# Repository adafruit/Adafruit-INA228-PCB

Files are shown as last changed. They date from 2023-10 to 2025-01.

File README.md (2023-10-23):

## Adafruit INA228 - I2C 85V, 20-bit High or Low Side Power Monitor - STEMMA QT / Qwiic PCB

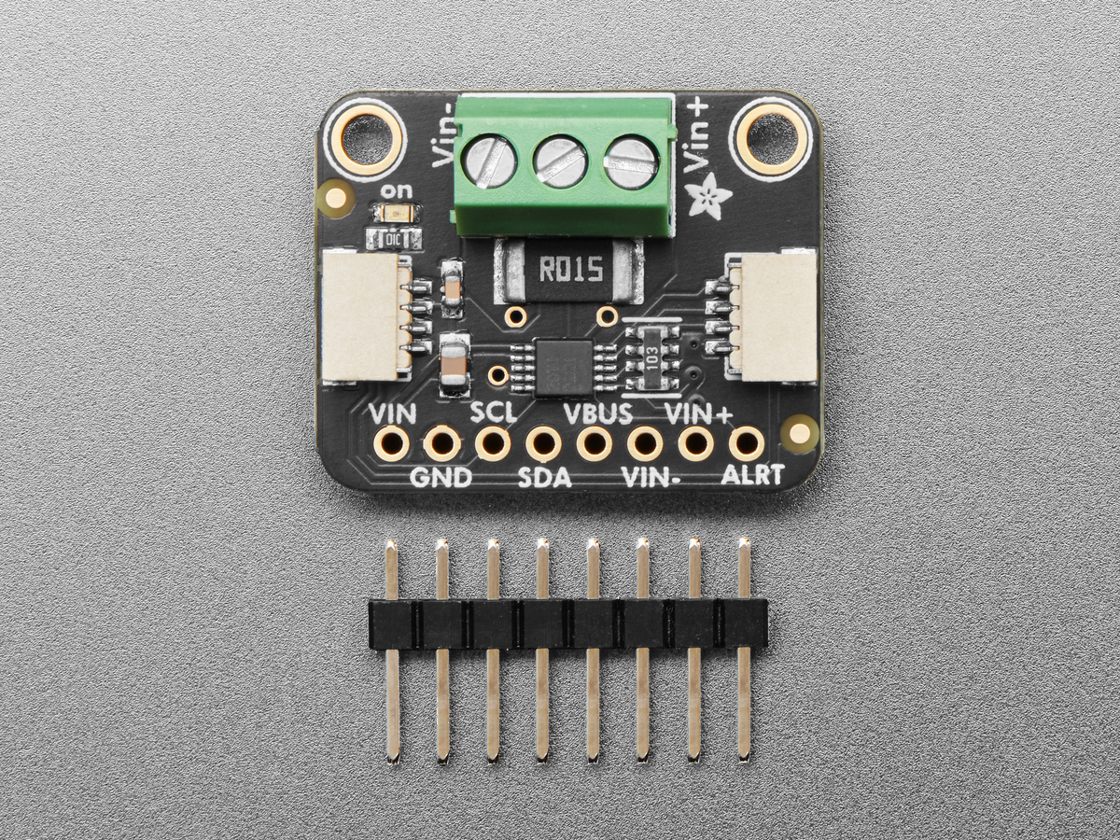
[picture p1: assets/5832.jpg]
<a href="http://www.adafruit.com/products/5832"><br/>
Click here to purchase one from the Adafruit shop</a>

PCB files for the Adafruit INA228 - I2C 85V, 20-bit High or Low Side Power Monitor - STEMMA QT / Qwiic. 

Format is EagleCAD schematic and board layout
* https://www.adafruit.com/product/5832

### Description

The INA228 is an amazing power monitoring chip, with best-of-everything support: up to 85VDC common-mode, high or low side measurements, 20-bit (!) ADC for precision measurements from milliamp to Amp, and I2C interface for easy configuration of alerts, oversampling, gain adjustments and more!

This breakout board may well be the last current sensing solution you every need to buy. Not only can it do the work of two multimeters, but it can do it with amazing precision and flexibility. With it you can measure high or low side DC current, the bus voltage, and have it automatically calculate the power. It can do so over impressive voltage, current, and temperature ranges with better than 1% accuracy, all while delivering the data in an easy to use format over I2C.

Works great with any microcontroller that is CircuitPython or Arduino compatible as well as single board computers such as the Raspberry Pi. It is compatible with 3V or 5V logic and can measure bus voltages up to +85VDC. Not for use with AC voltages.

Most current-measuring devices operate with some notable constraints that limit what they can be used for. Many are low-side only which can cause issues as the ground reference changes with current. Others like its little sister the INA219B avoid this by measuring on the high side but need to change their shunt resistor to measure different current ranges. The INA228 avoids these limitations, and with the precision 15milliohm shunt resistor on board, it can be used to measure as much as +85V at up to 10A (~10uA per LSB) or 2.75A (~2.5uA per LSB) Continuous on either the high or low side. Wow!

The voltage across the integrated 15 milliohm (.015 ohms!), 0.1% shunt resistor is measured by the internal 20 bit ADC, allowing for measurements over the impressive current range with a resolution of 10uA per LSB in high current measurement mode or 2.5uA per LSB in low current measurement mode.

In a high side configuration the bus voltage measurement and power calculation can be retrieved accurately, however advanced hackers wanting to measure bus voltage in a low side configuration will need to cut the jumper connecting V+ to VBUS and connect the VBUS pin to the voltage bus.

Comes as a fully assembled breakout board with a 3.5mm terminal block and header. Some light soldering is required to attach the header for use in a breadboard. 

### License

Adafruit invests time and resources providing this open source design, please support Adafruit and open-source hardware by purchasing products from [Adafruit](https://www.adafruit.com)!

Designed by Limor Fried/Ladyada for Adafruit Industries.

Creative Commons Attribution/Share-Alike, all text above must be included in any redistribution. 
See license.txt for additional details.

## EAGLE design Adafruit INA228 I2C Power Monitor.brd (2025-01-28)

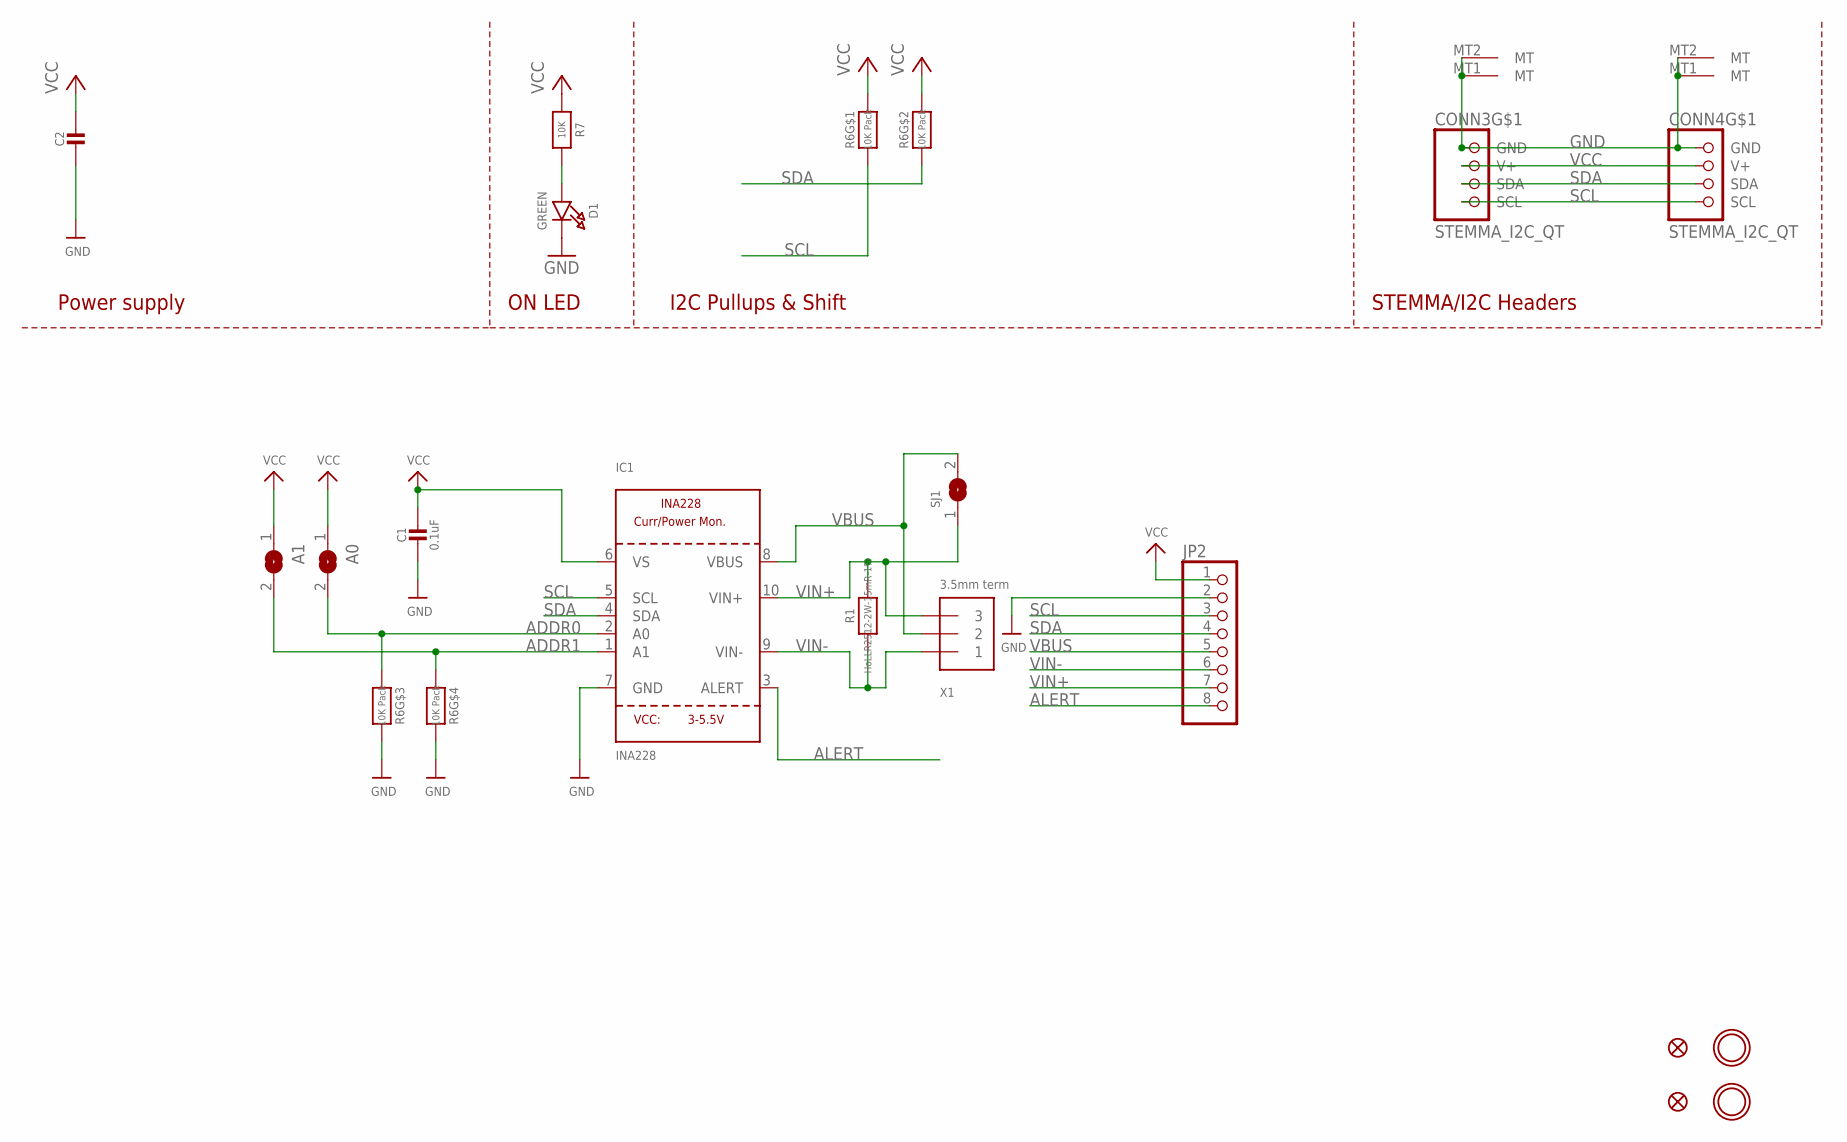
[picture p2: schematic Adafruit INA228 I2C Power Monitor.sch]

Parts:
A0, A1: SOLDERJUMPERREFLOW_NOPASTE; SOLDERJUMPER_REFLOW_NOPASTE
C1: 0.1uF; 0603-NO
C2: 10uF; 0805-NO
CONN3, CONN4: STEMMA_I2C_QT; JST_SH4
D1: GREEN; CHIPLED_0603_NOOUTLINE
FID3, FID4: FIDUCIAL_1MM
IC1: INA228; MSOP10
JP2: HEADER-1X870MIL; 1X08_ROUND_70
R1: HoLLR2512-2W-15mR-1%; 2512
R6: 10K Pack; RESPACK_4X0603
R7: 10K; 0603-NO
SJ1: SOLDERJUMPER; SOLDERJUMPER_ARROW_NOPASTE
U$20, U$21: MOUNTINGHOLE2.5; MOUNTINGHOLE_2.5_PLATED
X1: 3.5mm term; TERMBLOCK_1X3-3.5MM

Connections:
ADDR0: A0.2, IC1.2 (A0), R6.3 (1)
ADDR1: A1.2, IC1.1 (A1), R6.4 (1)
ALERT: IC1.3 (ALERT), JP2.8
GND: C1.2, C2.2, CONN3.1 (GND), CONN3.MT1 (MT), CONN3.MT2 (MT), CONN4.1 (GND), CONN4.MT1 (MT), CONN4.MT2 (MT), D1.C, IC1.7 (GND), JP2.2, R6.5 (2), R6.6 (2)
unnamed: D1.A, R7.2
SCL: CONN3.4 (SCL), CONN4.4 (SCL), IC1.5 (SCL), JP2.3, R6.1
SDA: CONN3.3 (SDA), CONN4.3 (SDA), IC1.4 (SDA), JP2.4, R6.2 (1)
VBUS: IC1.8 (VBUS), JP2.5, SJ1.2, X1.2
VCC: A0.1, A1.1, C1.1, C2.1, CONN3.2 (V+), CONN4.2 (V+), IC1.6 (VS), JP2.1, R6.7 (2), R6.8 (2), R7.1
VIN+: IC1.10 (VIN+), JP2.7, R1.2, SJ1.1, X1.3
VIN-: IC1.9 (VIN-), JP2.6, R1.1, X1.1

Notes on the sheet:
I2C Pullups & Shift
STEMMA/I2C Headers
ON LED
Power supply

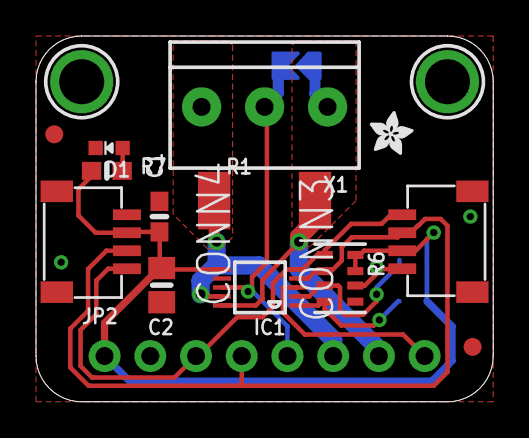
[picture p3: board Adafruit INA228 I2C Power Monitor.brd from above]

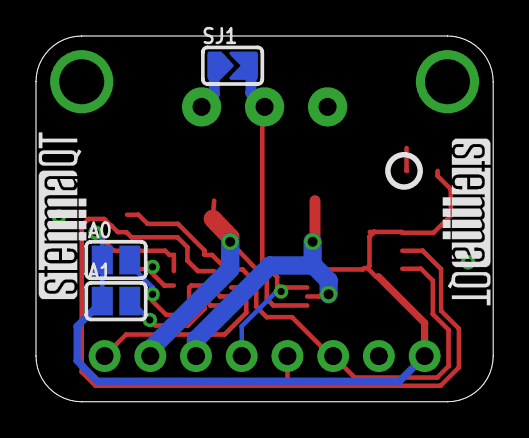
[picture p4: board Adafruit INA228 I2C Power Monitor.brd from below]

Board: 2 copper layers, 25.4 x 20.3 mm, 43 parts (16 on the bottom side), 11 nets.

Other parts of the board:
PLABEL0: PLABEL0
PLABEL1: PLABEL1
PLABEL2: PLABEL2
PLABEL3: PLABEL3
PLABEL4: PLABEL4
PLABEL5: PLABEL5
PLABEL6: PLABEL6
PLABEL7: PLABEL7
PLABEL8: PLABEL8
PLABEL9: PLABEL9
PLABEL10: PLABEL10
PLABEL11: PLABEL11
PLABEL12: PLABEL12
PLABEL13: PLABEL13
PLABEL14: PLABEL14
PLABEL15: PLABEL15
PLABEL16: PLABEL16
PLABEL17: PLABEL17
PLABEL18: PLABEL18
PLABEL19: PLABEL19
PLABEL20: PLABEL20
U$1: ADAFRUIT_2.5MM
U$30: PCBFEAT-REV-040
U$31, U$32: STEMMAQT

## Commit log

2023-10-23 cookiecutter output
    [Adafruit INA228 I2C Power Monitor.brd, Adafruit INA228 I2C Power Monitor.sch]
2025-01-28 rev C
    [Adafruit INA228 I2C Power Monitor.brd]
